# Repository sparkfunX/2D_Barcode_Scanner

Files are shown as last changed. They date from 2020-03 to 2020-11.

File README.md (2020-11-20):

2D Barcode Scanner Breakout
========================================

2D Barcode Scanner Breakout

[*2D Barcode Scanner Breakout (SPX-16441)*](https://www.sparkfun.com/products/16441)

The DYScan DE2120 is one of the coolest little barcode scanners we've ever seen. This tiny "scan engine" will read 20 different barcode symbologies — both 1D and 2D! This is achieved by using a camera coupled with on-board image processing to identify and decode everything from UPC codes to QR codes. The module also features two LEDs: one for illumination and one to project the red line that you're used to seeing from laser-based scanners. 

This breakout board makes it easy to explore all of the capabilities of the DE2120 without dealing with finicky flat flex cables. The scanner's USB interface is exposed via the on-board USB-C connector. A buzzer and status LED are connected to the module through appropriate drive circuits and a pushbutton tactile switch is provided on the "trigger" pin. When you're ready to incorporate the module into your embedded project, you can leverage the 5 pin header for direct access to the TTL serial pins, power pins, and trigger input.

The module can be configured either by using the serial interface or by scanning command barcodes found in the datasheet.

Repository Contents
-------------------
* **/Hardware** - Eagle design files (.brd, .sch)

Documentation
--------------
* [Schematic](https://cdn.sparkfun.com/assets/3/8/9/6/0/2D_Barcode_Scanner.pdf)
* [Datasheet](https://cdn.sparkfun.com/assets/6/4/6/1/f/DY_SCAN_Specification-DE2120_1___2_.pdf)
* [Settings Manual](https://cdn.sparkfun.com/assets/b/5/0/e/e/DY_Scan_Setting_Manual-DE2120___19.4.6___.pdf)
* [Eagle Files](https://cdn.sparkfun.com/assets/2/d/f/7/b/2DBarcodeScanner.zip)

License Information
-------------------

This product is _**open source**_! 

Please review the LICENSE.md file for license information. 

If you have any questions or concerns on licensing, please contact technical support on our [SparkFun forums](https://forum.sparkfun.com/viewforum.php?f=152).

Distributed as-is; no warranty is given.

- Your friends at SparkFun.

_<COLLABORATION CREDIT>_

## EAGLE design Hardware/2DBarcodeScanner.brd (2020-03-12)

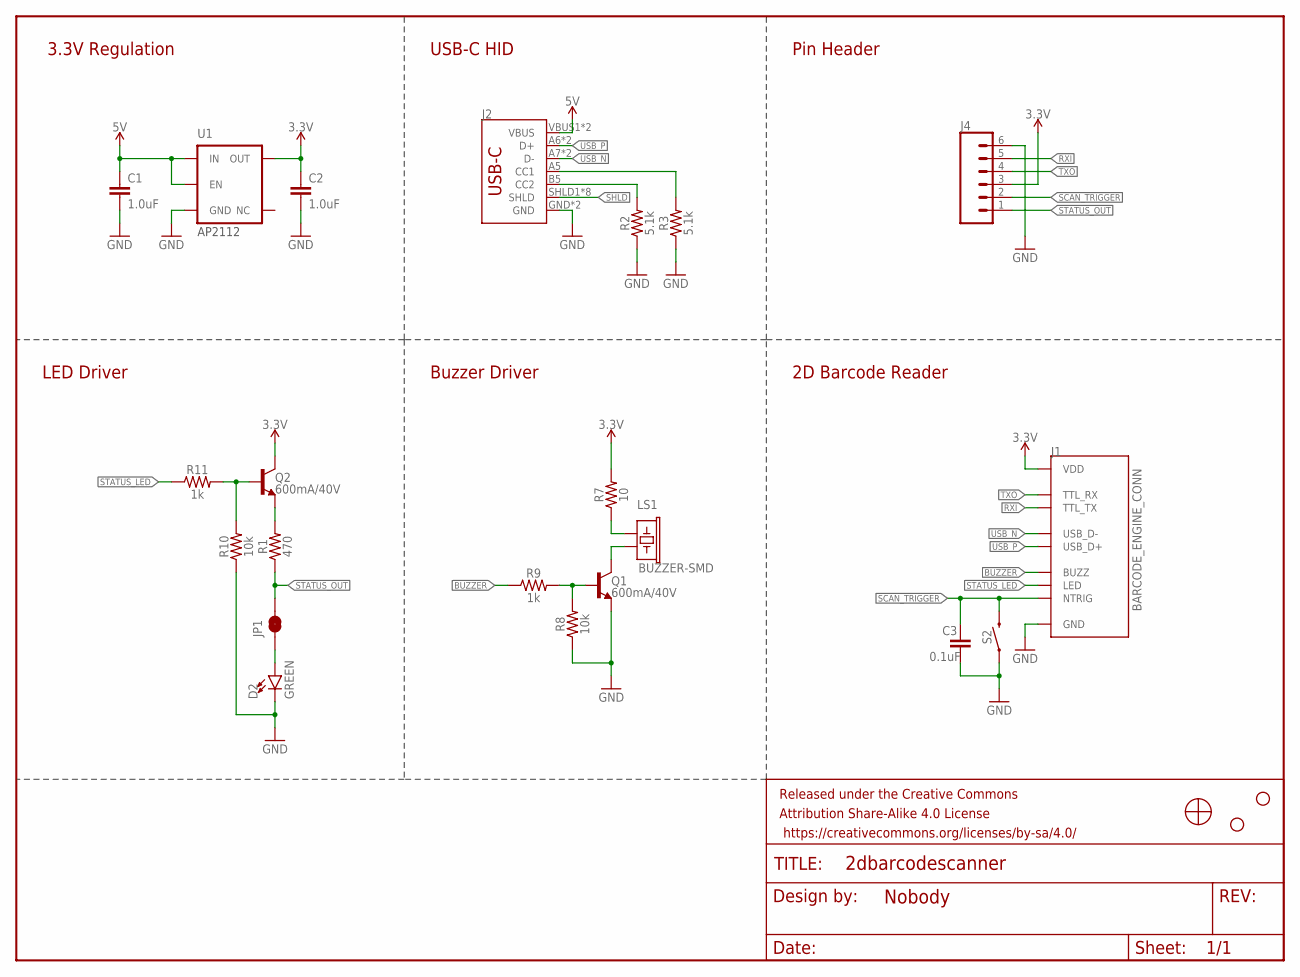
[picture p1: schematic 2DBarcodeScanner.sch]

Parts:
C1, C2: 1.0uF; 0603
C3: 0.1uF; 0603
D2: GREEN; LED-0603
FRAME1: FRAME-LETTERNO_PACKAGE; DUMMY
H2, H3: STAND-OFF
J1: BARCODE_ENGINE_CONN; CONN_FPC_BOTTOM_12POS_.5MM_R/A
J2: USB_C2-LAYER; USB-C-16P
J4: CONN_06NO_SILK_FEMALE_PTH; 1X06_NO_SILK
JP1: JUMPER-SMT_2_NC_TRACE_SILK; SMT-JUMPER_2_NC_TRACE_SILK
LS1: BUZZER-SMD; BUZZER-CCV
Q1, Q2: 600mA/40V; SOT23-3
R1: 470; 0603
R2, R3: 5.1k; 0603
R7: 10; 0603
R8, R10: 10k; 0603
R9, R11: 1k; 0603
S2: MOMENTARY-SWITCH-SPST-SMD-5.2MM-TALL; TACTILE_SWITCH_SMD_5.2MM
U1: 3.3V; SOT23-5
U$1: BARCODE_SCANNER_MOUNT

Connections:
3.3V: C2.1, J1.P$11 (VDD), J4.3, Q2.3 (C), R7.2, U1.5 (OUT)
5V: C1.1, J2.VBUS1 (VBUS), J2.VBUS2 (VBUS), U1.1 (IN), U1.3 (EN)
BUZZER: J1.P$4 (BUZZ), R9.1
CC3: J2.A5 (CC1), R3.2
CC4: J2.B5 (CC2), R2.2
GND: C1.2, C2.2, C3.2, D2.C, J1.P$10 (GND), J1.P$13 (GND), J1.P$14 (GND), J2.GND, J2.GND2 (GND), J4.6, Q1.2 (E), R2.1, R3.1, R8.1, R10.1, S2.1, U1.2 (GND)
unnamed: LS1.- (2), Q1.3 (C)
unnamed: LS1.+ (1), R7.1
unnamed: Q2.2 (E), R1.2
unnamed: Q1.1 (B), R8.2, R9.2
unnamed: Q2.1 (B), R10.2, R11.2
unnamed: D2.A, JP1.1
RXI: J1.P$8 (TTL_TX), J4.5
SCAN_TRIGGER: C3.1, J1.P$1 (NTRIG), J4.2, S2.3 (2)
SHLD: J2.SHLD1 (SHLD), J2.SHLD2 (SHLD), J2.SHLD3 (SHLD), J2.SHLD4 (SHLD), J2.SHLD5 (SHLD), J2.SHLD6 (SHLD), J2.SHLD7 (SHLD), J2.SHLD8 (SHLD)
STATUS_LED: J1.P$3 (LED), R11.1
STATUS_OUT: J4.1, JP1.2, R1.1
TXO: J1.P$9 (TTL_RX), J4.4
USB_N: J1.P$7 (USB_D-), J2.A7 (D-), J2.B7 (D-)
USB_P: J1.P$6 (USB_D+), J2.A6 (D+), J2.B6 (D+)

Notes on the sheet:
3.3V Regulation
AP2112
Pin Header
2D Barcode Reader
LED Driver
Buzzer Driver
USB-C HID

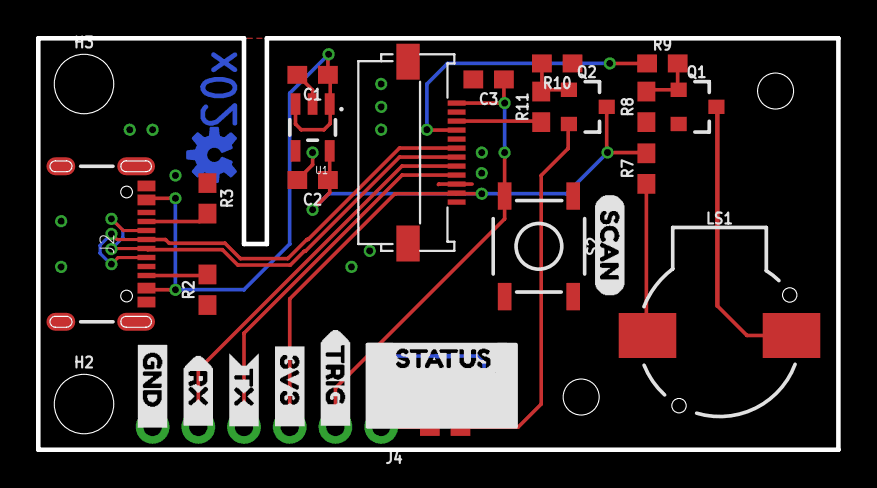
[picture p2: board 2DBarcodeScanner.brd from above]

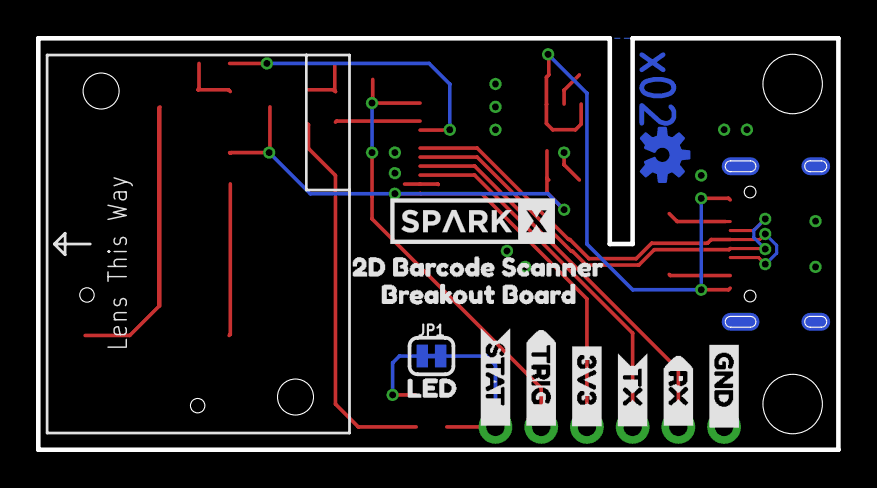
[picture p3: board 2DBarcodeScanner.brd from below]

Board: 2 copper layers, 44.5 x 22.9 mm, 43 parts (13 on the bottom side), 20 nets.

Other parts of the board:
U$2: STATUS3
U$3: STAT__5
U$4, U$5: TRIG__4
U$6, U$9: 3V3__3
U$7: SCAN4
U$8: LED0
U$10, U$11: TX__2
U$12, U$13: RX__1
U$14, U$15: GND__0
U$17: 2D_BARCODE_SCANNER0
U$18: BREAKOUT_BOARD1
U$20: SPARKX-MEDIUM
U$21: OSHW-LOGO-S_COPPER

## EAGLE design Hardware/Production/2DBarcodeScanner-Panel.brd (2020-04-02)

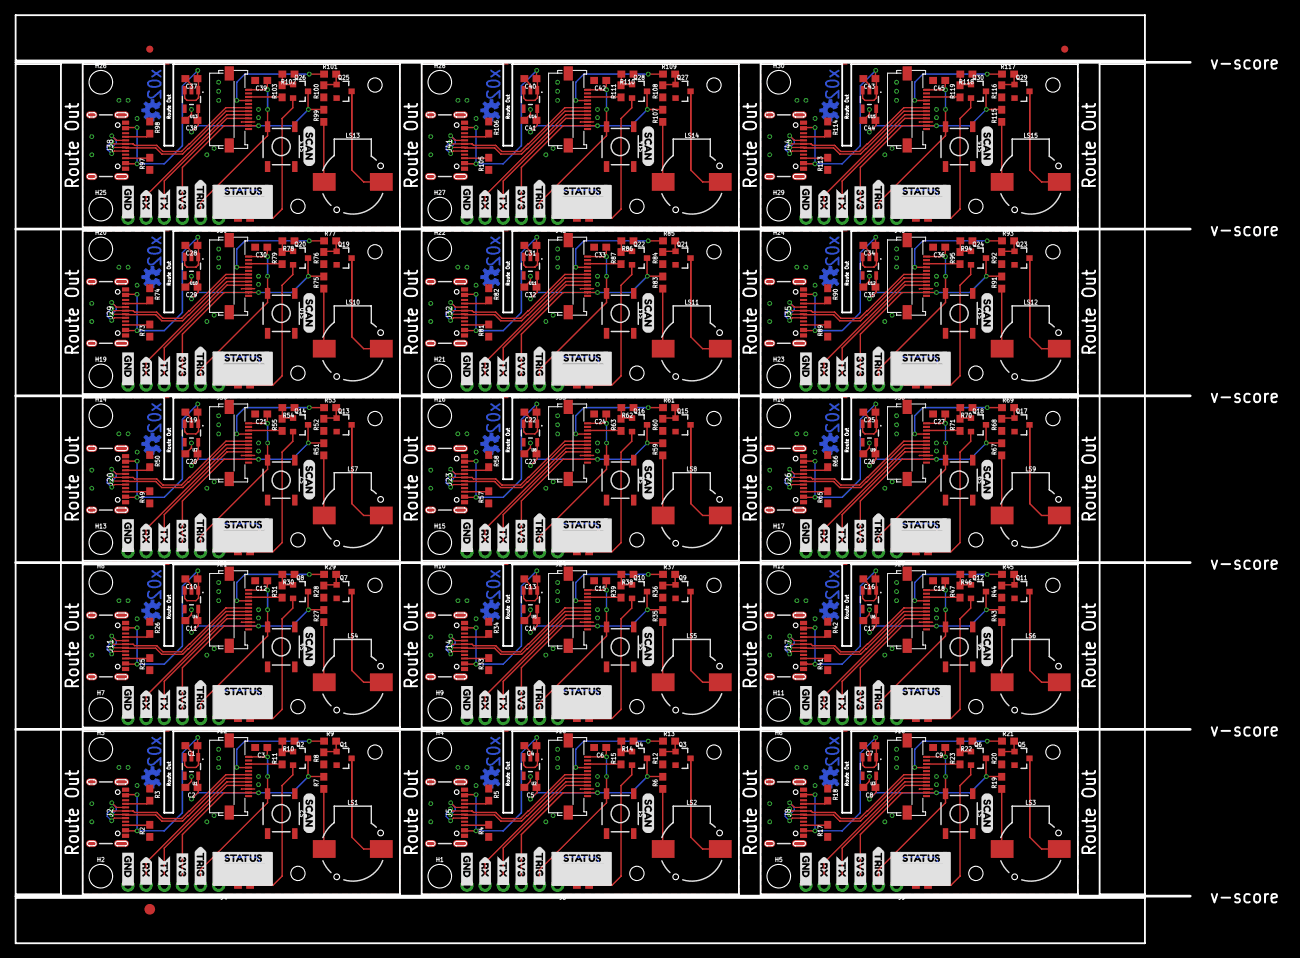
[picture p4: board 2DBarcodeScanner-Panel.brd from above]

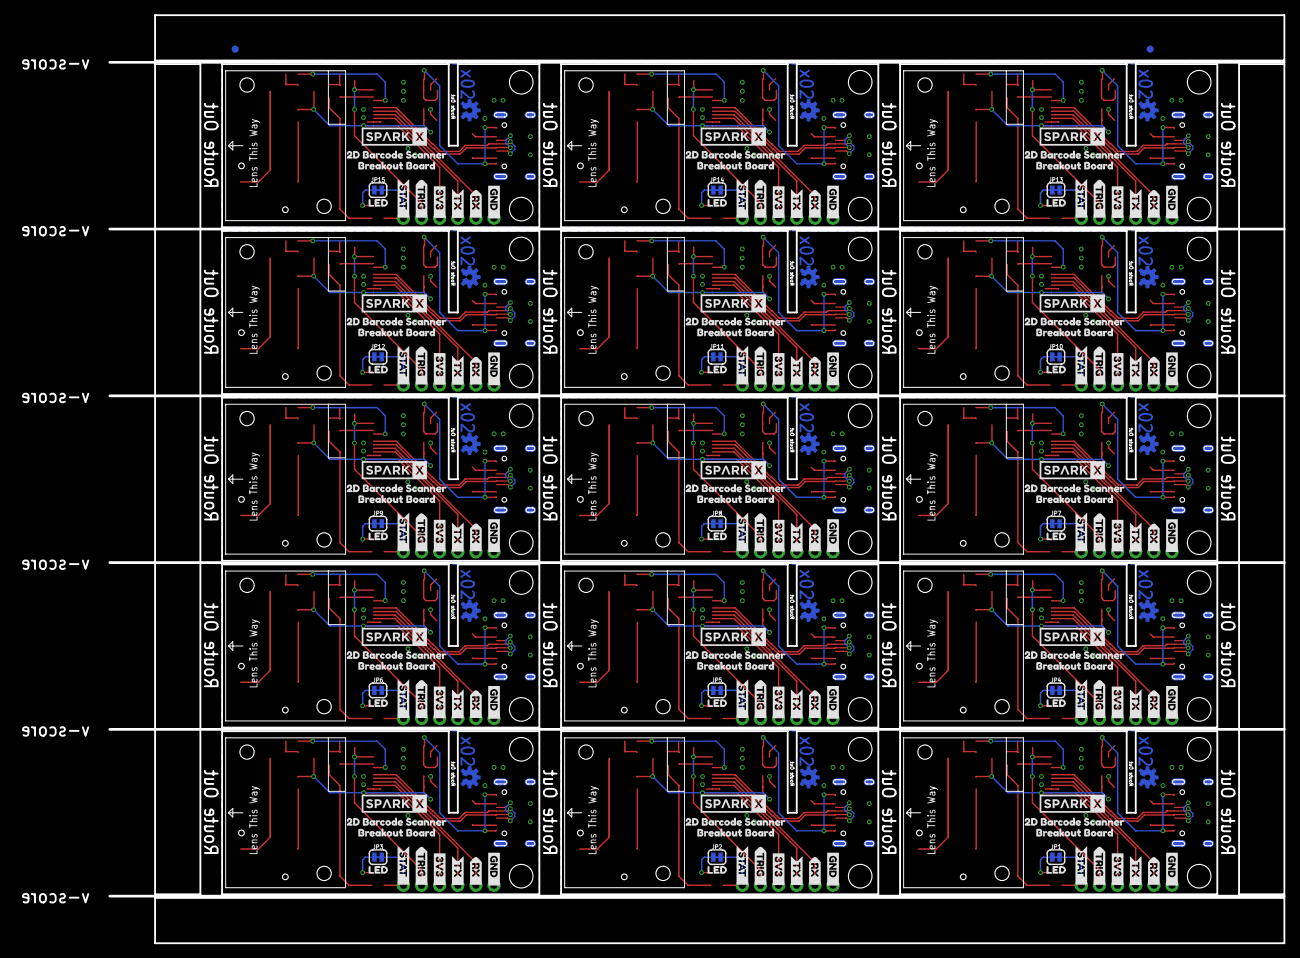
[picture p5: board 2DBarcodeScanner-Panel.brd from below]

Board: 2 copper layers, 164.6 x 130.0 mm, 650 parts (197 on the bottom side), 300 nets.

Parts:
C1, C2, C4, C5, C7, C8, C10, C11, C13, C14, C16, C17, C19, C20, C22, C23, C25, C26, C28, C29, C31, C32, C34, C35, C37, C38, C40, C41, C43, C44: 1.0uF; 0603
C3, C6, C9, C12, C15, C18, C21, C24, C27, C30, C33, C36, C39, C42, C45: 0.1uF; 0603
D1, D2, D3, D4, D5, D6, D7, D8, D9, D10, D11, D12, D13, D14, D15: GREEN; LED-0603
E$1, E$2, E$3, E$4: FIDUCIAL-1X2
E$5: FIDUCIAL-1.5X3
FRAME1, FRAME2, FRAME3, FRAME4, FRAME5, FRAME6, FRAME7, FRAME8, FRAME9, FRAME10, FRAME11, FRAME12, FRAME13, FRAME14, FRAME15: FRAME-LETTERNO_PACKAGE; DUMMY
H1, H2, H3, H4, H5, H6, H7, H8, H9, H10, H11, H12, H13, H14, H15, H16, H17, H18, H19, H20, H21, H22, H23, H24, H25, H26, H27, H28, H29, H30: STAND-OFF
J1, J3, J7, J10, J13, J16, J19, J22, J25, J28, J31, J34, J37, J40, J43: BARCODE_ENGINE_CONN; CONN_FPC_BOTTOM_12POS_.5MM_R/A
J2, J5, J8, J11, J14, J17, J20, J23, J26, J29, J32, J35, J38, J41, J44: USB-C-16P
J4, J6, J9, J12, J15, J18, J21, J24, J27, J30, J33, J36, J39, J42, J45: 1X06_NO_SILK
JP1, JP2, JP3, JP4, JP5, JP6, JP7, JP8, JP9, JP10, JP11, JP12, JP13, JP14, JP15: JUMPER-SMT_2_NC_TRACE_SILK; SMT-JUMPER_2_NC_TRACE_SILK
LS1, LS2, LS3, LS4, LS5, LS6, LS7, LS8, LS9, LS10, LS11, LS12, LS13, LS14, LS15: BUZZER-SMD; BUZZER-CCV
Q1, Q2, Q3, Q4, Q5, Q6, Q7, Q8, Q9, Q10, Q11, Q12, Q13, Q14, Q15, Q16, Q17, Q18, Q19, Q20, Q21, Q22, Q23, Q24, Q25, Q26, Q27, Q28, Q29, Q30: 600mA/40V; SOT23-3
R1, R16, R24, R32, R40, R48, R56, R64, R72, R80, R88, R96, R104, R112, R120: 470; 0603
R2, R3, R4, R5, R17, R18, R25, R26, R33, R34, R41, R42, R49, R50, R57, R58, R65, R66, R73, R74, R81, R82, R89, R90, R97, R98, R105, R106, R113, R114: 5.1k; 0603
R6, R7, R19, R27, R35, R43, R51, R59, R67, R75, R83, R91, R99, R107, R115: 10; 0603
R8, R10, R12, R14, R20, R22, R28, R30, R36, R38, R44, R46, R52, R54, R60, R62, R68, R70, R76, R78, R84, R86, R92, R94, R100, R102, R108, R110, R116, R118: 10k; 0603
R9, R11, R13, R15, R21, R23, R29, R31, R37, R39, R45, R47, R53, R55, R61, R63, R69, R71, R77, R79, R85, R87, R93, R95, R101, R103, R109, R111, R117, R119: 1k; 0603
S1, S2, S3, S4, S5, S6, S7, S8, S9, S10, S11, S12, S13, S14, S15: MOMENTARY-SWITCH-SPST-SMD-5.2MM-TALL; TACTILE_SWITCH_SMD_5.2MM
U1, U2, U3, U4, U5, U6, U7, U8, U9, U10, U11, U12, U13, U14, U15: 3.3V; SOT23-5
U$1, U$16, U$39, U$58, U$77, U$96, U$115, U$134, U$153, U$172, U$191, U$210, U$229, U$248, U$267: BARCODE_SCANNER_MOUNT
U$2, U$37, U$56, U$75, U$94, U$113, U$132, U$151, U$170, U$189, U$208, U$227, U$246, U$265, U$284: STATUS3
U$3, U$26, U$45, U$64, U$83, U$102, U$121, U$140, U$159, U$178, U$197, U$216, U$235, U$254, U$273: STAT__5
U$4, U$5, U$27, U$28, U$46, U$47, U$65, U$66, U$84, U$85, U$103, U$104, U$122, U$123, U$141, U$142, U$160, U$161, U$179, U$180, U$198, U$199, U$217, U$218, U$236, U$237, U$255, U$256, U$274, U$275: TRIG__4
U$6, U$9, U$29, U$30, U$48, U$49, U$67, U$68, U$86, U$87, U$105, U$106, U$124, U$125, U$143, U$144, U$162, U$163, U$181, U$182, U$200, U$201, U$219, U$220, U$238, U$239, U$257, U$258, U$276, U$277: 3V3__3
U$7, U$19, U$40, U$59, U$78, U$97, U$116, U$135, U$154, U$173, U$192, U$211, U$230, U$249, U$268: SCAN4
U$8, U$38, U$57, U$76, U$95, U$114, U$133, U$152, U$171, U$190, U$209, U$228, U$247, U$266, U$285: LED0
U$10, U$11, U$31, U$32, U$50, U$51, U$69, U$70, U$88, U$89, U$107, U$108, U$126, U$127, U$145, U$146, U$164, U$165, U$183, U$184, U$202, U$203, U$221, U$222, U$240, U$241, U$259, U$260, U$278, U$279: TX__2
U$12, U$13, U$33, U$34, U$52, U$53, U$71, U$72, U$90, U$91, U$109, U$110, U$128, U$129, U$147, U$148, U$166, U$167, U$185, U$186, U$204, U$205, U$223, U$224, U$242, U$243, U$261, U$262, U$280, U$281: RX__1
U$14, U$15, U$35, U$36, U$54, U$55, U$73, U$74, U$92, U$93, U$111, U$112, U$130, U$131, U$149, U$150, U$168, U$169, U$187, U$188, U$206, U$207, U$225, U$226, U$244, U$245, U$263, U$264, U$282, U$283: GND__0
U$17, U$22, U$41, U$60, U$79, U$98, U$117, U$136, U$155, U$174, U$193, U$212, U$231, U$250, U$269: 2D_BARCODE_SCANNER0
U$18, U$23, U$42, U$61, U$80, U$99, U$118, U$137, U$156, U$175, U$194, U$213, U$232, U$251, U$270: BREAKOUT_BOARD1
U$20, U$24, U$43, U$62, U$81, U$100, U$119, U$138, U$157, U$176, U$195, U$214, U$233, U$252, U$271: SPARKX-MEDIUM
U$21, U$25, U$44, U$63, U$82, U$101, U$120, U$139, U$158, U$177, U$196, U$215, U$234, U$253, U$272: OSHW-LOGO-S_COPPER

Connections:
3.3V: C2.1, J1.P$11, J4.3, Q2.3, R7.2, U1.5
3.3V1: C5.1, J3.P$11, J6.3, Q4.3, R6.2, U2.5
3.3V2: C8.1, J7.P$11, J9.3, Q6.3, R19.2, U3.5
3.3V3: C11.1, J10.P$11, J12.3, Q8.3, R27.2, U4.5
3.3V4: C14.1, J13.P$11, J15.3, Q10.3, R35.2, U5.5
3.3V5: C17.1, J16.P$11, J18.3, Q12.3, R43.2, U6.5
3.3V6: C20.1, J19.P$11, J21.3, Q14.3, R51.2, U7.5
3.3V7: C23.1, J22.P$11, J24.3, Q16.3, R59.2, U8.5
3.3V8: C26.1, J25.P$11, J27.3, Q18.3, R67.2, U9.5
3.3V9: C29.1, J28.P$11, J30.3, Q20.3, R75.2, U10.5
3.3V10: C32.1, J31.P$11, J33.3, Q22.3, R83.2, U11.5
3.3V11: C35.1, J34.P$11, J36.3, Q24.3, R91.2, U12.5
3.3V12: C38.1, J37.P$11, J39.3, Q26.3, R99.2, U13.5
3.3V13: C41.1, J40.P$11, J42.3, Q28.3, R107.2, U14.5
3.3V14: C44.1, J43.P$11, J45.3, Q30.3, R115.2, U15.5
5V: C1.1, J2.VBUS1, J2.VBUS2, U1.1, U1.3
5V1: C4.1, J5.VBUS1, J5.VBUS2, U2.1, U2.3
5V2: C7.1, J8.VBUS1, J8.VBUS2, U3.1, U3.3
5V3: C10.1, J11.VBUS1, J11.VBUS2, U4.1, U4.3
5V4: C13.1, J14.VBUS1, J14.VBUS2, U5.1, U5.3
5V5: C16.1, J17.VBUS1, J17.VBUS2, U6.1, U6.3
5V6: C19.1, J20.VBUS1, J20.VBUS2, U7.1, U7.3
5V7: C22.1, J23.VBUS1, J23.VBUS2, U8.1, U8.3
5V8: C25.1, J26.VBUS1, J26.VBUS2, U9.1, U9.3
5V9: C28.1, J29.VBUS1, J29.VBUS2, U10.1, U10.3
5V10: C31.1, J32.VBUS1, J32.VBUS2, U11.1, U11.3
5V11: C34.1, J35.VBUS1, J35.VBUS2, U12.1, U12.3
5V12: C37.1, J38.VBUS1, J38.VBUS2, U13.1, U13.3
5V13: C40.1, J41.VBUS1, J41.VBUS2, U14.1, U14.3
5V14: C43.1, J44.VBUS1, J44.VBUS2, U15.1, U15.3
BUZZER: J1.P$4, R9.1
BUZZER1: J3.P$4, R13.1
BUZZER2: J7.P$4, R21.1
BUZZER3: J10.P$4, R29.1
BUZZER4: J13.P$4, R37.1
BUZZER5: J16.P$4, R45.1
BUZZER6: J19.P$4, R53.1
BUZZER7: J22.P$4, R61.1
BUZZER8: J25.P$4, R69.1
BUZZER9: J28.P$4, R77.1
BUZZER10: J31.P$4, R85.1
BUZZER11: J34.P$4, R93.1
BUZZER12: J37.P$4, R101.1
BUZZER13: J40.P$4, R109.1
BUZZER14: J43.P$4, R117.1
CC1: J5.A5, R5.2
CC2: J5.B5, R4.2
CC3: J2.A5, R3.2
CC4: J2.B5, R2.2
CC5: J8.A5, R18.2
CC6: J8.B5, R17.2
CC7: J11.A5, R26.2
CC8: J11.B5, R25.2
CC9: J14.A5, R34.2
CC10: J14.B5, R33.2
CC11: J17.A5, R42.2
CC12: J17.B5, R41.2
CC13: J20.A5, R50.2
CC14: J20.B5, R49.2
CC15: J23.A5, R58.2
CC16: J23.B5, R57.2
CC17: J26.A5, R66.2
CC18: J26.B5, R65.2
CC19: J29.A5, R74.2
CC20: J29.B5, R73.2
CC21: J32.A5, R82.2
CC22: J32.B5, R81.2
CC23: J35.A5, R90.2
CC24: J35.B5, R89.2
CC25: J38.A5, R98.2
CC26: J38.B5, R97.2
CC27: J41.A5, R106.2
CC28: J41.B5, R105.2
CC29: J44.A5, R114.2
CC30: J44.B5, R113.2
GND: C1.2, C2.2, C3.2, D2.C, J1.P$10, J1.P$13, J1.P$14, J2.GND, J2.GND2, J4.6, Q1.2, R2.1, R3.1, R8.1, R10.1, S2.1, U1.2
GND1: C4.2, C5.2, C6.2, D1.C, J3.P$10, J3.P$13, J3.P$14, J5.GND, J5.GND2, J6.6, Q3.2, R4.1, R5.1, R12.1, R14.1, S1.1, U2.2
GND2: C7.2, C8.2, C9.2, D3.C, J7.P$10, J7.P$13, J7.P$14, J8.GND, J8.GND2, J9.6, Q5.2, R17.1, R18.1, R20.1, R22.1, S3.1, U3.2
GND3: C10.2, C11.2, C12.2, D4.C, J10.P$10, J10.P$13, J10.P$14, J11.GND, J11.GND2, J12.6, Q7.2, R25.1, R26.1, R28.1, R30.1, S4.1, U4.2
GND4: C13.2, C14.2, C15.2, D5.C, J13.P$10, J13.P$13, J13.P$14, J14.GND, J14.GND2, J15.6, Q9.2, R33.1, R34.1, R36.1, R38.1, S5.1, U5.2
GND5: C16.2, C17.2, C18.2, D6.C, J16.P$10, J16.P$13, J16.P$14, J17.GND, J17.GND2, J18.6, Q11.2, R41.1, R42.1, R44.1, R46.1, S6.1, U6.2
GND6: C19.2, C20.2, C21.2, D7.C, J19.P$10, J19.P$13, J19.P$14, J20.GND, J20.GND2, J21.6, Q13.2, R49.1, R50.1, R52.1, R54.1, S7.1, U7.2
GND7: C22.2, C23.2, C24.2, D8.C, J22.P$10, J22.P$13, J22.P$14, J23.GND, J23.GND2, J24.6, Q15.2, R57.1, R58.1, R60.1, R62.1, S8.1, U8.2
GND8: C25.2, C26.2, C27.2, D9.C, J25.P$10, J25.P$13, J25.P$14, J26.GND, J26.GND2, J27.6, Q17.2, R65.1, R66.1, R68.1, R70.1, S9.1, U9.2
GND9: C28.2, C29.2, C30.2, D10.C, J28.P$10, J28.P$13, J28.P$14, J29.GND, J29.GND2, J30.6, Q19.2, R73.1, R74.1, R76.1, R78.1, S10.1, U10.2
GND10: C31.2, C32.2, C33.2, D11.C, J31.P$10, J31.P$13, J31.P$14, J32.GND, J32.GND2, J33.6, Q21.2, R81.1, R82.1, R84.1, R86.1, S11.1, U11.2
GND11: C34.2, C35.2, C36.2, D12.C, J34.P$10, J34.P$13, J34.P$14, J35.GND, J35.GND2, J36.6, Q23.2, R89.1, R90.1, R92.1, R94.1, S12.1, U12.2
GND12: C37.2, C38.2, C39.2, D13.C, J37.P$10, J37.P$13, J37.P$14, J38.GND, J38.GND2, J39.6, Q25.2, R97.1, R98.1, R100.1, R102.1, S13.1, U13.2
GND13: C40.2, C41.2, C42.2, D14.C, J40.P$10, J40.P$13, J40.P$14, J41.GND, J41.GND2, J42.6, Q27.2, R105.1, R106.1, R108.1, R110.1, S14.1, U14.2
GND14: C43.2, C44.2, C45.2, D15.C, J43.P$10, J43.P$13, J43.P$14, J44.GND, J44.GND2, J45.6, Q29.2, R113.1, R114.1, R116.1, R118.1, S15.1, U15.2
unnamed: LS2.-, Q3.3
unnamed: LS1.-, Q1.3
unnamed: LS1.+, R7.1
unnamed: Q2.2, R1.2
unnamed: Q1.1, R8.2, R9.2
unnamed: LS2.+, R6.1
unnamed: Q2.1, R10.2, R11.2
unnamed: D2.A, JP1.1
unnamed: Q3.1, R12.2, R13.2
unnamed: Q4.2, R16.2
unnamed: Q4.1, R14.2, R15.2
unnamed: D1.A, JP2.1
unnamed: LS3.-, Q5.3
unnamed: LS3.+, R19.1
unnamed: Q5.1, R20.2, R21.2
unnamed: Q6.2, R24.2
unnamed: Q6.1, R22.2, R23.2
unnamed: D3.A, JP3.1
unnamed: LS4.-, Q7.3
unnamed: LS4.+, R27.1
unnamed: Q7.1, R28.2, R29.2
unnamed: Q8.2, R32.2
unnamed: Q8.1, R30.2, R31.2
unnamed: D4.A, JP4.1
unnamed: LS5.-, Q9.3
unnamed: LS5.+, R35.1
unnamed: Q9.1, R36.2, R37.2
unnamed: Q10.2, R40.2
unnamed: Q10.1, R38.2, R39.2
unnamed: D5.A, JP5.1
unnamed: LS6.-, Q11.3
unnamed: LS6.+, R43.1
unnamed: Q11.1, R44.2, R45.2
unnamed: Q12.2, R48.2
unnamed: Q12.1, R46.2, R47.2
unnamed: D6.A, JP6.1
unnamed: LS7.-, Q13.3
unnamed: LS7.+, R51.1
unnamed: Q13.1, R52.2, R53.2
unnamed: Q14.2, R56.2
unnamed: Q14.1, R54.2, R55.2
unnamed: D7.A, JP7.1
unnamed: LS8.-, Q15.3
unnamed: LS8.+, R59.1
unnamed: Q15.1, R60.2, R61.2
unnamed: Q16.2, R64.2
unnamed: Q16.1, R62.2, R63.2
unnamed: D8.A, JP8.1
unnamed: LS9.-, Q17.3
unnamed: LS9.+, R67.1
unnamed: Q17.1, R68.2, R69.2
unnamed: Q18.2, R72.2
unnamed: Q18.1, R70.2, R71.2
unnamed: D9.A, JP9.1
unnamed: LS10.-, Q19.3
unnamed: LS10.+, R75.1
unnamed: Q19.1, R76.2, R77.2
unnamed: Q20.2, R80.2
unnamed: Q20.1, R78.2, R79.2
unnamed: D10.A, JP10.1
unnamed: LS11.-, Q21.3
unnamed: LS11.+, R83.1
unnamed: Q21.1, R84.2, R85.2
unnamed: Q22.2, R88.2
unnamed: Q22.1, R86.2, R87.2
unnamed: D11.A, JP11.1
unnamed: LS12.-, Q23.3
unnamed: LS12.+, R91.1
unnamed: Q23.1, R92.2, R93.2
unnamed: Q24.2, R96.2
unnamed: Q24.1, R94.2, R95.2
unnamed: D12.A, JP12.1
unnamed: LS13.-, Q25.3
unnamed: LS13.+, R99.1
unnamed: Q25.1, R100.2, R101.2
unnamed: Q26.2, R104.2
unnamed: Q26.1, R102.2, R103.2
unnamed: D13.A, JP13.1
unnamed: LS14.-, Q27.3
unnamed: LS14.+, R107.1
unnamed: Q27.1, R108.2, R109.2
unnamed: Q28.2, R112.2
unnamed: Q28.1, R110.2, R111.2
unnamed: D14.A, JP14.1
unnamed: LS15.-, Q29.3
unnamed: LS15.+, R115.1
unnamed: Q29.1, R116.2, R117.2
unnamed: Q30.2, R120.2
unnamed: Q30.1, R118.2, R119.2
unnamed: D15.A, JP15.1
RXI: J1.P$8, J4.5
RXI1: J3.P$8, J6.5
RXI2: J7.P$8, J9.5
RXI3: J10.P$8, J12.5
RXI4: J13.P$8, J15.5
RXI5: J16.P$8, J18.5
RXI6: J19.P$8, J21.5
RXI7: J22.P$8, J24.5
RXI8: J25.P$8, J27.5
RXI9: J28.P$8, J30.5
RXI10: J31.P$8, J33.5
RXI11: J34.P$8, J36.5
RXI12: J37.P$8, J39.5
RXI13: J40.P$8, J42.5
RXI14: J43.P$8, J45.5
SCAN_TRIGGER: C3.1, J1.P$1, J4.2, S2.3
SCAN_TRIGGER1: C6.1, J3.P$1, J6.2, S1.3
SCAN_TRIGGER2: C9.1, J7.P$1, J9.2, S3.3
SCAN_TRIGGER3: C12.1, J10.P$1, J12.2, S4.3
SCAN_TRIGGER4: C15.1, J13.P$1, J15.2, S5.3
SCAN_TRIGGER5: C18.1, J16.P$1, J18.2, S6.3
SCAN_TRIGGER6: C21.1, J19.P$1, J21.2, S7.3
SCAN_TRIGGER7: C24.1, J22.P$1, J24.2, S8.3
SCAN_TRIGGER8: C27.1, J25.P$1, J27.2, S9.3
SCAN_TRIGGER9: C30.1, J28.P$1, J30.2, S10.3
SCAN_TRIGGER10: C33.1, J31.P$1, J33.2, S11.3
SCAN_TRIGGER11: C36.1, J34.P$1, J36.2, S12.3
SCAN_TRIGGER12: C39.1, J37.P$1, J39.2, S13.3
SCAN_TRIGGER13: C42.1, J40.P$1, J42.2, S14.3
SCAN_TRIGGER14: C45.1, J43.P$1, J45.2, S15.3
SHLD: J2.SHLD1, J2.SHLD2, J2.SHLD3, J2.SHLD4, J2.SHLD5, J2.SHLD6, J2.SHLD7, J2.SHLD8
SHLD1: J5.SHLD1, J5.SHLD2, J5.SHLD3, J5.SHLD4, J5.SHLD5, J5.SHLD6, J5.SHLD7, J5.SHLD8
SHLD2: J8.SHLD1, J8.SHLD2, J8.SHLD3, J8.SHLD4, J8.SHLD5, J8.SHLD6, J8.SHLD7, J8.SHLD8
SHLD3: J11.SHLD1, J11.SHLD2, J11.SHLD3, J11.SHLD4, J11.SHLD5, J11.SHLD6, J11.SHLD7, J11.SHLD8
SHLD4: J14.SHLD1, J14.SHLD2, J14.SHLD3, J14.SHLD4, J14.SHLD5, J14.SHLD6, J14.SHLD7, J14.SHLD8
SHLD5: J17.SHLD1, J17.SHLD2, J17.SHLD3, J17.SHLD4, J17.SHLD5, J17.SHLD6, J17.SHLD7, J17.SHLD8
SHLD6: J20.SHLD1, J20.SHLD2, J20.SHLD3, J20.SHLD4, J20.SHLD5, J20.SHLD6, J20.SHLD7, J20.SHLD8
SHLD7: J23.SHLD1, J23.SHLD2, J23.SHLD3, J23.SHLD4, J23.SHLD5, J23.SHLD6, J23.SHLD7, J23.SHLD8
SHLD8: J26.SHLD1, J26.SHLD2, J26.SHLD3, J26.SHLD4, J26.SHLD5, J26.SHLD6, J26.SHLD7, J26.SHLD8
SHLD9: J29.SHLD1, J29.SHLD2, J29.SHLD3, J29.SHLD4, J29.SHLD5, J29.SHLD6, J29.SHLD7, J29.SHLD8
SHLD10: J32.SHLD1, J32.SHLD2, J32.SHLD3, J32.SHLD4, J32.SHLD5, J32.SHLD6, J32.SHLD7, J32.SHLD8
SHLD11: J35.SHLD1, J35.SHLD2, J35.SHLD3, J35.SHLD4, J35.SHLD5, J35.SHLD6, J35.SHLD7, J35.SHLD8
SHLD12: J38.SHLD1, J38.SHLD2, J38.SHLD3, J38.SHLD4, J38.SHLD5, J38.SHLD6, J38.SHLD7, J38.SHLD8
SHLD13: J41.SHLD1, J41.SHLD2, J41.SHLD3, J41.SHLD4, J41.SHLD5, J41.SHLD6, J41.SHLD7, J41.SHLD8
SHLD14: J44.SHLD1, J44.SHLD2, J44.SHLD3, J44.SHLD4, J44.SHLD5, J44.SHLD6, J44.SHLD7, J44.SHLD8
STATUS_LED: J1.P$3, R11.1
STATUS_LED1: J3.P$3, R15.1
STATUS_LED2: J7.P$3, R23.1
STATUS_LED3: J10.P$3, R31.1
STATUS_LED4: J13.P$3, R39.1
STATUS_LED5: J16.P$3, R47.1
STATUS_LED6: J19.P$3, R55.1
STATUS_LED7: J22.P$3, R63.1
STATUS_LED8: J25.P$3, R71.1
STATUS_LED9: J28.P$3, R79.1
STATUS_LED10: J31.P$3, R87.1
STATUS_LED11: J34.P$3, R95.1
STATUS_LED12: J37.P$3, R103.1
STATUS_LED13: J40.P$3, R111.1
STATUS_LED14: J43.P$3, R119.1
STATUS_OUT: J4.1, JP1.2, R1.1
STATUS_OUT1: J6.1, JP2.2, R16.1
STATUS_OUT2: J9.1, JP3.2, R24.1
STATUS_OUT3: J12.1, JP4.2, R32.1
STATUS_OUT4: J15.1, JP5.2, R40.1
STATUS_OUT5: J18.1, JP6.2, R48.1
STATUS_OUT6: J21.1, JP7.2, R56.1
STATUS_OUT7: J24.1, JP8.2, R64.1
STATUS_OUT8: J27.1, JP9.2, R72.1
STATUS_OUT9: J30.1, JP10.2, R80.1
STATUS_OUT10: J33.1, JP11.2, R88.1
STATUS_OUT11: J36.1, JP12.2, R96.1
STATUS_OUT12: J39.1, JP13.2, R104.1
STATUS_OUT13: J42.1, JP14.2, R112.1
STATUS_OUT14: J45.1, JP15.2, R120.1
TXO: J1.P$9, J4.4
TXO1: J3.P$9, J6.4
TXO2: J7.P$9, J9.4
TXO3: J10.P$9, J12.4
TXO4: J13.P$9, J15.4
TXO5: J16.P$9, J18.4
TXO6: J19.P$9, J21.4
TXO7: J22.P$9, J24.4
TXO8: J25.P$9, J27.4
TXO9: J28.P$9, J30.4
TXO10: J31.P$9, J33.4
TXO11: J34.P$9, J36.4
TXO12: J37.P$9, J39.4
TXO13: J40.P$9, J42.4
TXO14: J43.P$9, J45.4
USB_N: J1.P$7, J2.A7, J2.B7
USB_N1: J3.P$7, J5.A7, J5.B7
USB_N2: J7.P$7, J8.A7, J8.B7
USB_N3: J10.P$7, J11.A7, J11.B7
USB_N4: J13.P$7, J14.A7, J14.B7
USB_N5: J16.P$7, J17.A7, J17.B7
USB_N6: J19.P$7, J20.A7, J20.B7
USB_N7: J22.P$7, J23.A7, J23.B7
USB_N8: J25.P$7, J26.A7, J26.B7
USB_N9: J28.P$7, J29.A7, J29.B7
USB_N10: J31.P$7, J32.A7, J32.B7
USB_N11: J34.P$7, J35.A7, J35.B7
USB_N12: J37.P$7, J38.A7, J38.B7
USB_N13: J40.P$7, J41.A7, J41.B7
USB_N14: J43.P$7, J44.A7, J44.B7
USB_P: J1.P$6, J2.A6, J2.B6
USB_P1: J3.P$6, J5.A6, J5.B6
USB_P2: J7.P$6, J8.A6, J8.B6
USB_P3: J10.P$6, J11.A6, J11.B6
USB_P4: J13.P$6, J14.A6, J14.B6
USB_P5: J16.P$6, J17.A6, J17.B6
USB_P6: J19.P$6, J20.A6, J20.B6
USB_P7: J22.P$6, J23.A6, J23.B6
USB_P8: J25.P$6, J26.A6, J26.B6
USB_P9: J28.P$6, J29.A6, J29.B6
USB_P10: J31.P$6, J32.A6, J32.B6
USB_P11: J34.P$6, J35.A6, J35.B6
USB_P12: J37.P$6, J38.A6, J38.B6
USB_P13: J40.P$6, J41.A6, J41.B6
USB_P14: J43.P$6, J44.A6, J44.B6

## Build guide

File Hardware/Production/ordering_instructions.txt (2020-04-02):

panel size, 159x124mm
PCB thickness, 1.6mm
number of layers, 2
soldermask color, Black
silkscreen color, White
oz copper, 1oz
finish, HASL lead free
stencils, top+bottom
pcs per panel, 15
min trace width, 0.1778mm / 0.0070in
min drill size, 0.3810mm / 0.0150in

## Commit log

2019-12-13 x01 panels ordered
    [2DBarcodeScanner-Panel.GBL, 2DBarcodeScanner-Panel.GBO, 2DBarcodeScanner-Panel.GBS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]
2020-03-12 Version x02
    [2DBarcodeScanner-Panel.GBL, 2DBarcodeScanner-Panel.GBO, 2DBarcodeScanner-Panel.GBS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]
2020-03-12 Forgot to pull that stupid diode
    [2DBarcodeScanner.brd, 2DBarcodeScanner.sch]
2020-03-12 Adding panel files x02
    [2DBarcodeScanner-Panel.GBL, 2DBarcodeScanner-Panel.GBO, 2DBarcodeScanner-Panel.GBP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]

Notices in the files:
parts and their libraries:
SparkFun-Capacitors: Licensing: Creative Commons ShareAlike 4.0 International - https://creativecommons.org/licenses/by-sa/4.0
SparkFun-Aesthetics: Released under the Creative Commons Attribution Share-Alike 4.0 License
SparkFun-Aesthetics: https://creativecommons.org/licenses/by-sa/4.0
